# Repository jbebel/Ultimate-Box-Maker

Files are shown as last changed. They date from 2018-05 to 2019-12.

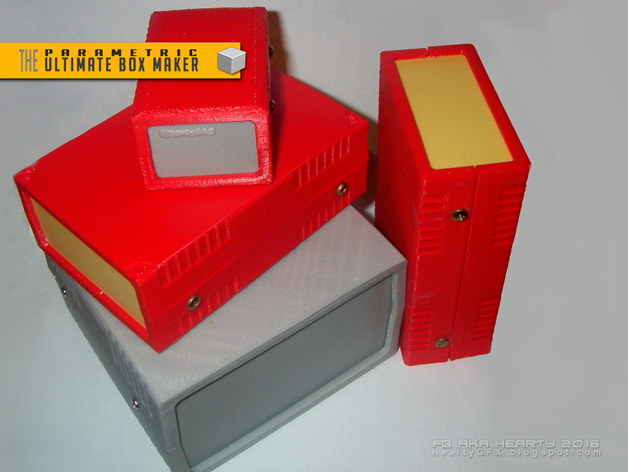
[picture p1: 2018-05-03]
images/dfdf5ceb28a5a7c63daad8bfc72fc554_preview_featured.jpg

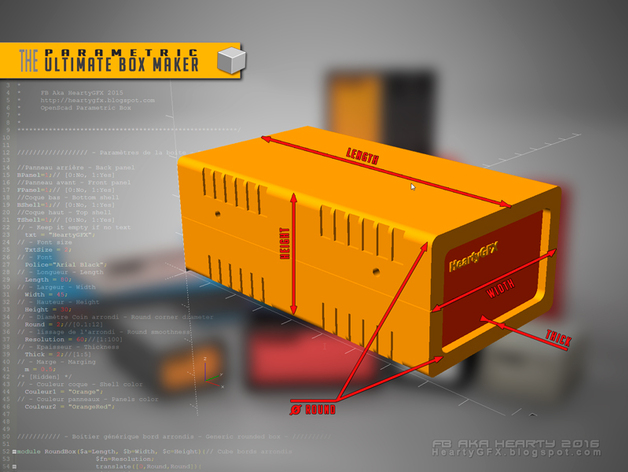
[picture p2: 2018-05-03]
images/5c2528d7dc69dc743380f6c7ddb887d5_preview_featured.jpg

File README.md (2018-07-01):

# Ultimate-Box-Maker
Ultimate Box Maker

This is copied from https://www.thingiverse.com/thing:1264391 under the creative commons license with modifications logged here.
It is publised as a remix on Thingiverse at https://www.thingiverse.com/thing:2938921

Box design originally by:
////////////////////////////////////////////////////////////////////
              -    FB Aka Heartman/Hearty 2016     -
              -   http://heartygfx.blogspot.com    -
              -       OpenScad Parametric Box      -
              -         CC BY-NC 3.0 License       -
////////////////////////////////////////////////////////////////////

Improved by jbebel:
http://github.com/jbebel/Ultimate-Box-Maker

To create a box, start by modifying the numerical parameters in the sections
below. This can be accomplished using a release of OpenSCAD newer than 2015.03.
As of the time of writing, this means that a development snapshot is required.
The Thingiverse Customizer may also potentially work, but at the time of
writing, it was inoperable.

The simplest choice is to hand-edit the .scad file. Feature toggles are
annotated with a comment. The other numerical parameters are measurements in
mm. Everything is parametrized, so if you double all the non-feature parameters
you will double the box size in every dimension. Certain parameters are derived
from other parameters. If you wish to override them, you may, but sensible
defaults have been chosen. Notably the design in this revision is particularly
PCB-centric, in that you should start with your PCB size and adjust the margins
around it to determine the box size. If you care more about the box size, you
can set the Length, Width, and Height explicitly, but read the comments around
them.

Once your box is sized appropriately, you can use the Panel modules to design
the holes and text for the front and back panels. Helper variables are provided
to assist you in positioning these holes relative to the PCB, if your holes are
for PCB-mounted components.

When you are ready to print, adjust the values in the "STL element to export"
section, and export each part one at a time.

Experimental options are provided for a screwless design, but these are
untested. In particular, the box fixation tabs may need thicknesses adjusted
in order to have the appropriate flexibility.

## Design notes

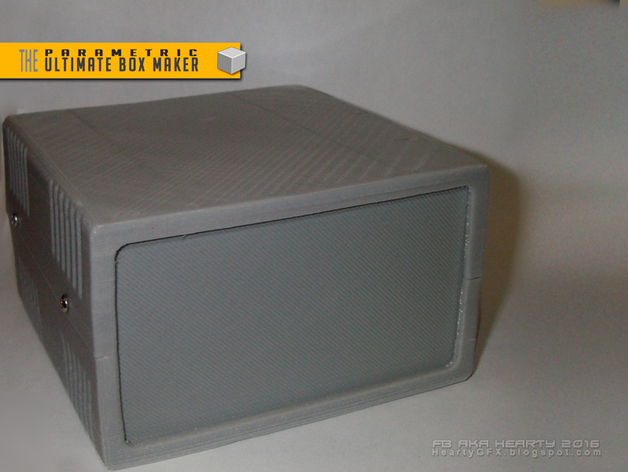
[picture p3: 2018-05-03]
images/74d1fa52020ccdc66438833ef1dfb658_preview_featured.jpg

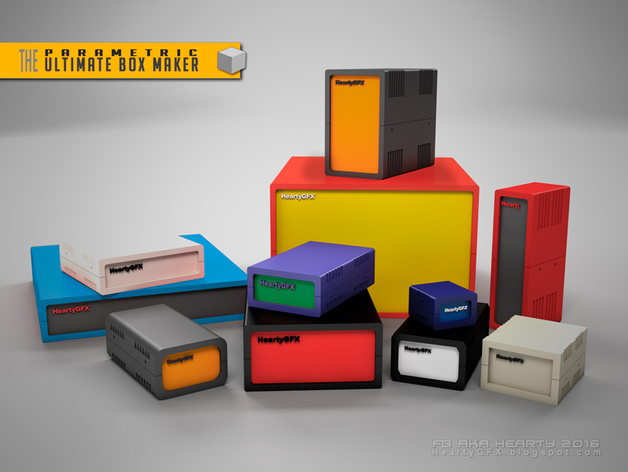
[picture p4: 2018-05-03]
images/bd4fbbd9aa4da913eb2d5eac3920107e_preview_featured.jpg

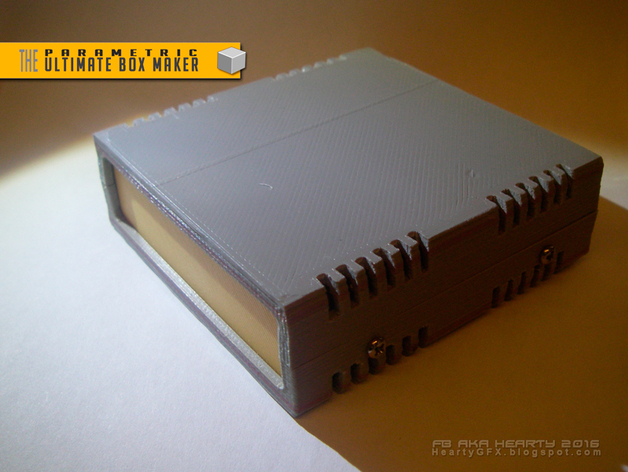
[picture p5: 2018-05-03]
images/9b60c601c6d0bcd0837e3c9c51fbf55f_preview_featured.jpg

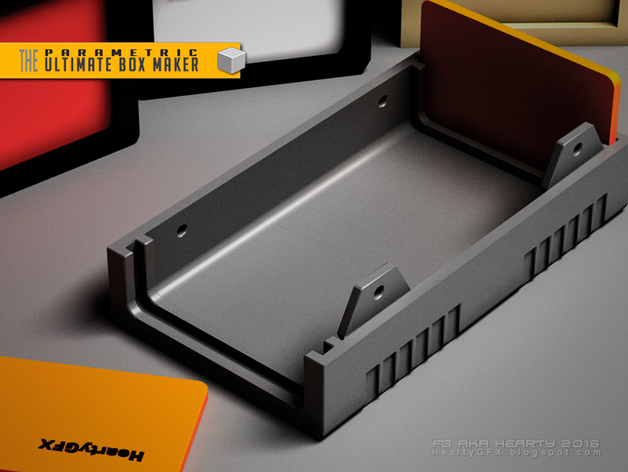
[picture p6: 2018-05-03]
images/7efb17c56cb85ef8a36d71741ac642c0_preview_featured.jpg

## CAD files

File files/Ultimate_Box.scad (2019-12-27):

/* Box design originally by:
////////////////////////////////////////////////////////////////////
              -    FB Aka Heartman/Hearty 2016     -
              -   http://heartygfx.blogspot.com    -
              -       OpenScad Parametric Box      -
              -         CC BY-NC 3.0 License       -
////////////////////////////////////////////////////////////////////

Improved by jbebel:
http://github.com/jbebel/Ultimate-Box-Maker

To create a box, start by modifying the numerical parameters in the sections
below. This can be accomplished using a release of OpenSCAD newer than 2015.03.
As of the time of writing, this means that a development snapshot is required.
The Thingiverse Customizer may also potentially work, but at the time of
writing, it was inoperable.

The simplest choice is to hand-edit the .scad file. Feature toggles are
annotated with a comment. The other numerical parameters are measurements in
mm. Everything is parametrized, so if you double all the non-feature parameters
you will double the box size in every dimension. Certain parameters are derived
from other parameters. If you wish to override them, you may, but sensible
defaults have been chosen. Notably the design in this revision is particularly
PCB-centric, in that you should start with your PCB size and adjust the margins
around it to determine the box size. If you care more about the box size, you
can set the Length, Width, and Height explicitly, but read the comments around
them.

Once your box is sized appropriately, you can use the Panel modules to design
the holes and text for the front and back panels. Helper variables are provided
to assist you in positioning these holes relative to the PCB, if your holes are
for PCB-mounted components.

When you are ready to print, adjust the values in the "STL element to export"
section, and export each part one at a time.

Experimental options are provided for a screwless design, but these are
untested. In particular, the box fixation tabs may need thicknesses adjusted
in order to have the appropriate flexibility.
*/

// preview[view:north east, tilt:top diagonal]
//----------------------- Box parameters ---------------------------

/* [Box options] */
// - Wall thickness
Thick = 2;
// - Panel thickness
PanelThick = 2;
// - Font Thickness
FontThick = 0.5;
// - Filet Radius
Filet = 2;
// - 0 for beveled, 1 for rounded
Round = 1; // [0:No, 1:Yes]
// - Printer margin around interior cutouts
CutoutMargin = 0.3;
// - Margin between mating parts
PartMargin = 0.1;
// - PCB feet? (x4)
PCBFeet = 1; // [0:No, 1:Yes]
// - Decorations?
Decorations = 1; // [0:No, 1:Yes]
// - Decorations to ventilation holes
Vent = 1; // [0:No, 1:Yes]
// - Decoration-Holes width (in mm)
Vent_width = 1.5;
// - Tolerance (Panel/rails gap on one edge)
PanelThickGap = CutoutMargin + PartMargin;
PanelVerticalGap = PartMargin;
PanelHorizontalGap = CutoutMargin + PartMargin;


/* [Box Fixation Tabs] */
// - Side screw hole (or snap) diameter
ScrewHole = 2.2606;
// - Screw thread major diameter for outer shell
BoxHole = 2.8448;
// Thickness of fixation tabs
TabThick = 2;
// Back left tab
BLTab = 1; // [0:Bottom, 1:Top]
// Back right tab
BRTab = 1; // [0:Bottom, 1:Top]
// Front left tab
FLTab = 1; // [0:Bottom, 1:Top]
// Front right tab
FRTab = 1; // [0:Bottom, 1:Top]
// EXPERIMENTAL: Snap tabs
SnapTabs = 0; // [0:Screws, 1:Snaps]


/* [PCB options] */
// - PCB Length
PCBLength = 80;
// - PCB Width
PCBWidth = 144;
// - PCB Thickness
PCBThick = 1.6;
// You likely need to maintain |TabThick| margin on the left and right for tabs
// and whatnot.
// - Margin between front panel and PCB
FrontEdgeMargin = 70;
// - Margin between back panel and PCB
BackEdgeMargin = 0;
// - Margin between left wall and PCB
LeftEdgeMargin = 11;
// - Margin between right wall and PCB
RightEdgeMargin = 11;
// - Margin between top of PCB and box top.
TopMargin = 84;


/* [PCB_Feet] */
// - Foot height above box interior
FootHeight = 8;
// - Foot diameter
FootDia = 8;
// - Hole diameter, or peg for screwless design
FootHole = 2.2606; // tap size for #4 coarse-thread
// - EXPERIMENTAL Screwless design
Screwless = 0; // [0:Screws, 1:Screwless]
FootFilet = FootHeight/4;

// Foot centers are specified as distance from PCB back-left corner.
// X is along the "length" axis, and Y is along the "width" axis.
// - Foot 1 distance from back PCB edge
Foot1X = 5;
// - Foot 1 distance from left PCB edge
Foot1Y = 5;
// - Foot 2 distance from back PCB edge
Foot2X = 5;
// - Foot 2 distance from right PCB edge
Foot2YFromEdge = 5;
Foot2Y = PCBWidth - Foot2YFromEdge;
// - Foot 3 distance from front PCB edge
Foot3XFromEdge = 5;
Foot3X = PCBLength - Foot3XFromEdge;
// - Foot 3 distance from left PCB edge
Foot3Y = 5;
// - Foot 4 distance from front PCB edge
Foot4XFromEdge = 5;
Foot4X = PCBLength - Foot4XFromEdge;
// - Foot 4 distance from right PCB edge
Foot4YFromEdge = 5;
Foot4Y = PCBWidth - Foot4YFromEdge;


/* [STL element to export] */
// - Top shell
TShell = 0; // [0:No, 1:Yes]
// - Bottom shell
BShell = 1; // [0:No, 1:Yes]
// - Front panel
FPanL = 1; // [0:No, 1:Yes]
// - Back panel
BPanL = 1; // [0:No, 1:Yes]
// - Panel holes and text
PanelFeatures = 0; // [0:No, 1:Yes]


/* [Hidden] */
// - Shell color
Couleur1 = "Orange";
// - Panel color
Couleur2 = "OrangeRed";
// - Text color
TextColor = "White";
// - making decorations thicker if it is a vent to make sure they go through
// shell
// Add a small number to Thick in case Filet is 0.
Dec_Thick = Vent ? Thick*1.001 + Filet : Thick/2;
// Separate vents with a square pillar by default.
Dec_Spacing = Thick + Vent_width;
// X offset to center of first vent
Dec_Offset = Thick*2 + PanelThick + PanelThickGap*2 + Dec_Spacing - Vent_width/2;

// Resolution based on Round parameter. Set this first number to something
// smaller to speed up processing. It should always be a multiple of 4.
Resolution = Round ? 100: 4;

/* Calculate box dimensions from PCB. If you want a more box-centric design
   where the outer diameter of the box matters more than the margins around
   the PCB you can set these manually. The PCB will still be placedaccording
   to the left and back margins, and if you want to use the screwless box
   design, you will need to set the TopMargin to
   (Height - Thick*2 - FootHeight - PCBThick)
*/
Length = PCBLength + FrontEdgeMargin + BackEdgeMargin + ((Thick + PanelThick + PanelThickGap*2)*2);
Width = PCBWidth + LeftEdgeMargin + RightEdgeMargin + Thick*2;
Height = FootHeight + PCBThick + TopMargin + Thick*2;
echo("Box: ", Length=Length, Width=Width, Height=Height);
// X position inset of mounting holes and tabs
MountInset = Thick*3 + PanelThick + PanelThickGap*2 + ScrewHole*4;

// Calculate panel dimensions from box dimensions.
PanelWidth = Width - Thick*2 - PanelHorizontalGap*2;
PanelHeight = Height - Thick*2 - PanelVerticalGap*2;


/*  Panel Manager

    Use the below 4 modules to produce holes and text on the front and back
    panels. The holes modules should contain instances of SquareHole or
    CylinderHole defined later in this file. The text modules should contain
    instances of LText or CText defined later in this file. It is
    recommended to use variables that you define for your needs to create
    the size and positions of these objects.
*/

// Calculate board-relative positions with respect to the panel, for
// convenience in placing panel elements.
TopOfBoardWRTPanel = FootHeight + PCBThick - PanelVerticalGap;
LeftEdgeOfBoardWRTFPanel = LeftEdgeMargin - PanelHorizontalGap;
LeftEdgeOfBoardWRTBPanel = RightEdgeMargin - PanelHorizontalGap;
// Visible panel edges
PanelBottomEdge = Thick - PanelVerticalGap;
PanelTopEdge = PanelHeight - Thick + PanelVerticalGap;
PanelLeftEdge = Thick - PanelHorizontalGap;
PanelRightEdge = PanelWidth - Thick + PanelHorizontalGap;


// Holes for front panel
module FPanelHoles() {
    // SquareHole(On/Off, Xpos,Ypos,Length,Width,Filet)
    SquareHole(1, 20, 20, 15, 10, 1);
    SquareHole(1, 40, 20, 15, 10, 1);
    SquareHole(1, 60, 20, 15, 10, 1);
    // CylinderHole(On/Off, Xpos, Ypos, Diameter)
    CylinderHole(1, 27, 40, 8);
    CylinderHole(1, 47, 40, 8);
    CylinderHole(1, 67, 40, 8);
    SquareHole(1, 20, 50, 80, 30, 3);
    CylinderHole(1, 93, 30, 10);
    SquareHole(1, 120, 20, 30, 60, 3);
}


// Text for front panel
module FPanelText() {
    // LText(On/Off, Xpos, Ypos, "Font", Size, "Text", "HAlign", "VAlign")
    LText(1, 20, 83, "Arial Black", 4, "Digital Screen", HAlign="left");
    LText(1, 120, 83, "Arial Black", 4, "Level", HAlign="left");
    LText(1, 20, 11, "Arial Black", 6, "  1     2      3", HAlign="left");
    // CText(On/Off, Xpos, Ypos, "Font", Size, Diameter, Arc(Deg), Starting Angle(Deg),"Text")
    CText(1, 93, 29, "Arial Black", 4, 10, 180, 0,
          ["1", "." , "3", "." , "5", "." , "7", "." , "9", "." , "11"]);
}
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

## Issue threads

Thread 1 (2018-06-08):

Make outer-shell screw holes larger

jbebel, 2018-06-08:
So that screws only firmly attach to inner box and can hold the outer box tightly in place.

Closed 2018-06-19.

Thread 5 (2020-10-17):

Adding some features

oiram55, 2020-10-17:
Hello,
here the box-maker with some add's

added air slots to Panels / Padding for text, if air slots are selected
Mounting holes on top
Cable holes on back
[U_Box_V103_M.zip](https://github.com/jbebel/Ultimate-Box-Maker/files/5396591/U_Box_V103_M.zip)

panel

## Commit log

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2018-05-03 Use consistent indenting
    Chose 4 spaces because the OpenSCAD editor uses that by default.
    [U_Box_V104_Test_Cleaned.scad]
2018-05-04 Put all if blocks in curly braces and use spacing
    Following style guide at https://www.thingiverse.com/thing:12768
    [U_Box_V104_Test_Cleaned.scad]
2018-05-04 Improve spacing
    Add/remove lots of spacing for consistency. Add/remove a few parenthesis
    for arithmetic readability.
    Actually undo previous spacing because I disagree with the style guide
    referenced previously.
    [U_Box_V104_Test_Cleaned.scad]
2018-05-04 Call all functions in a consistent style.
    Fixed a few minor issues in the process (typoed "square" in previous
    commit")
    Put curly braces around blocks that didn't have them for consistency.
    Notably, re-ordered arguments for "cylinder" since the manual says if
    you have named arguments, all following arguments must be named. So now
    all cylinders have the height first, unnamed, followed by either r= or
    d=, and then $fn= if it isn't otherwise specified in the block.
    [U_Box_V104_Test_Cleaned.scad]
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2018-05-04 Add module documentation
    Before each module, describe the function and inputs
    Also added a few comments identifying block endings.
    Added a missing space after a "for".
    [U_Box_V104_Test_Cleaned.scad]
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2018-05-06 Add editable back panel support
    Holes and letters can be added to the back the same as the front.
    Calculate PanelWidth and PanelHeight from parameters and use globally.
    [U_Box_V104_Test_Cleaned.scad]
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2018-05-07 Calculate dimensions from PCB and margins
    Add parameters for PCB size and margins on all sides.
    Generate the box dimensions from these sizes.
    Place the PCB appropriately based on the margins.
    This has a change in definition, as the previous PCB size was the size
    of the square made by the mounting holes. Now it is the size of the
    actual PCB.
    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
    [U_Box_V104_Test_Cleaned.scad]
2018-05-07 minor fixes
    Removed parens for style consistency.
    Fixied call to color() to be consistent with other calls.
    [U_Box_V104_Test_Cleaned.scad]
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2018-05-07 Calculate foot positions parametrically
    Add paramaters for X and Y positions of all 4 feet.
    Use those when creating feet relative to the board position.
    [U_Box_V104_Test_Cleaned.scad]
2018-05-08 Use FootHeight as height above box interior.
    It is also the depth of the screw hole, which is likely how it will be
    calculated.
    [U_Box_V104_Test_Cleaned.scad]
2018-05-08 Add a PCBThick parameter
    Use it to calculate the top margin from the top of the board.
    Draw the transparent board with appropriate thickness
    Provide convenience variables for board position on panel.
    [U_Box_V104_Test_Cleaned.scad]
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2018-05-08 Set hole sizes and CutoutMargin
    Add ScrewHole and FootHole parameters
    Set them to #4 coarse thread size.
    Use them in appropriate places on tabs and feet
    Add CutoutMargin parameter as a margin around interior cutouts.
    Apply it to foot, CylinderHole, and SquareHole
    [U_Box_V104_Test_Cleaned.scad]
2018-05-09 Remove Thick = Thick*2
    The Coque module was setting Thick = Thick*2 which causes confusion
    while reading, likelihood of errors, and difficulty in modification.
    I removed this, and replace every invocation with Thick*2, simplifying
    where appropriate. This is largely in preparation of separating Panel
    thickness from Thick.
    [U_Box_V104_Test_Cleaned.scad]
2018-05-09 Center the interior box
    The interior box (fins for holding the panel) was oddly not centered.
    Shift it using the proper parameters for it to be centered.
    It also was shifted vertically by 0.1 to remove "the artifact" I'm not
    sure what this artifact is, so I'm removing the shift until I see reason
    not to. It also makes the interior hole of the feet shorter by 0.1 and
    the tolerance under the board 0.1 less, so it seems a bit wrong to have
    in place.
    [U_Box_V104_Test_Cleaned.scad]
2018-05-09 Large rail box decreased in vertical height.
    While it has no impact on the outcome, the large outer box was taller
    than it needed to be, and didn't accurately represent the box size when
    debugged. This was probably an error of the Thick = Thick*2 change.
    [U_Box_V104_Test_Cleaned.scad]
2018-05-09 Scale upper cutout cube to thickness
    Rather than fixed 100
    [U_Box_V104_Test_Cleaned.scad]
2018-05-09 Also fix height of interior through-box
    [U_Box_V104_Test_Cleaned.scad]
2018-05-09 Remove some unnecessary shifting of cutouts
    The 45 degree box for the bottom angled cutout of the box tabs was
    unnecessarily shifted.
    The rectangular cutout for the sides of the tabs was unnecessarily wide,
    and the margin depended on the thickness, which doesn't make much sense.
    It depends more on the printer, so this margin should be parametrized in
    a later CL.
    [U_Box_V104_Test_Cleaned.scad]
2018-05-09 Support PanelThick different from Thick
    If PanelThick is equal to Thick, all is the same. If it is different,
    then only the ends are scaled. Everything in the middle, including box
    decorations and feet remain in the same position relative to the
    interior of the panels.
    [U_Box_V104_Test_Cleaned.scad]
2018-05-09 Fix position of front panel
    [U_Box_V104_Test_Cleaned.scad]
2018-05-09 Center box decorations on the box.
    Previously they were shifted to the front by half the vent width. This
    should be better parametrized still. Particularly the closeness to the
    edge.
    [U_Box_V104_Test_Cleaned.scad]
2018-05-09 Support taller feet
    Make the foot exterior cutout square as tall as FootHeight.
    Previously making it taller than 100 made the top wider.
    This is obviously ridiculous, but no harder to do right, and looks nicer
    when debugging.
    [U_Box_V104_Test_Cleaned.scad]
2018-05-09 Support FootFilet in parameters
    Default it to Thick so it scales with the box.
    [U_Box_V104_Test_Cleaned.scad]
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2018-05-09 Shorten some long lines.
    [U_Box_V104_Test_Cleaned.scad]
2018-05-09 Support holes in thicker panels
    Panel cutouts were limited to 10mm. Scale them by PanelThick to make
    debugging more appealing and support ridiculously thick panels.
    [U_Box_V104_Test_Cleaned.scad]
2018-05-14 Minor spacing fixes.
    [U_Box_V104_Test_Cleaned.scad]
2018-05-14 Add a boolean parameter for Round
    Use it to set either a round or beveled corner. Use it for RoundBox,
    Panel, and the feet edge.
    Set all other circles (except the tabs) to fn=100 for smoothness.
    [U_Box_V104_Test_Cleaned.scad]
2018-05-14 Add comment for Round parameter
    With this comment, it appears as a boolean in the customizer.
    [U_Box_V104_Test_Cleaned.scad]
2018-05-14 Remove an extra echo and fix spacing/comments
    [U_Box_V104_Test_Cleaned.scad]
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2018-05-14 Stop translating text by 0.5 and back again.
    I suspect this was an artifact before text was linear_extruded, as it
    has a default thickness of 1, so shifting by 0.5 placed it on the
    surface. Linear extrude was added, and then the calls to LText and CText
    were shifted the other direction by 0.5 to get them on the surface. This
    now just results in two unnecessary translates, so I've removed them.
    I also removed the shift from the "PCB" text. It's thickness has no
    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
    [U_Box_V104_Test_Cleaned.scad]
2018-05-14 Unify text() arguments.
    Re-order arguments to match docs and be consistent.
    Remove valign from CText, as baseline was the default value.
    Remove an unnecessary space.
    [U_Box_V104_Test_Cleaned.scad]
2018-05-14 Support VAlign for LText
    Add new argument that defaults to baseline.
    Update comments to describe the new option.
    Update some HAlign documentation with more details.
    [U_Box_V104_Test_Cleaned.scad]
2018-05-14 fix ridiculous font thickness used in testing
    [U_Box_V104_Test_Cleaned.scad]
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2018-05-15 Re-work of vent/decoration holes
    Make all vent holes Thick + Filet thick so they extend to the end of the
    rounded corner, particularly for large filets, but not too far in for
    small filets.
    Make all decorations Thick/2 so they scale with the thickness.
    Separate the vents by a square Thick x Thick pillar.
    Generate the position of the first vent/decoration based on the panel
    thickness, wall thickness, margin, and vent spacing so that there is one
    pillar's width beteween the interior edge and the first vent.
    Bring the decoration/vent in from 1mm outside the box both horizontally
    and vertically to prevent artifacts. This does result in vents reaching
    under the box farther than previously, bu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
    [U_Box_V104_Test_Cleaned.scad]
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2018-05-16 Re-work panel, roundbox, and SquareHole
    Do the minkowski in 2D so that if Filet is 0, and half the minkowski is
    null, you don't have to fix the height. Then translate, extrude, and
    rotate it.
    [U_Box_V104_Test_Cleaned.scad]
2018-05-16 Use "offset" instead of minkowski with a circle
    The last change didn't work if Filet is 0. minkowski didn't work well
    with a 2D null argument either. This is a better solution, plus it saves
    a line.
    The preview works fine, but there's still an issue with the full render.
    [U_Box_V104_Test_Cleaned.scad]
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2018-05-16 Improve subtraction on interior rails
    There was some artifacting and errors resulting from the inner rails not
    producing a valid 2-manifold object. Make the rails larger so they
    interect the box, and make the subtraction the full height and width of
    the box so the boundary isn't indeterminate.
    [U_Box_V104_Test_Cleaned.scad]
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2018-05-16 Adjust holes based on wall thickness
    Rather than fixed at 20mm, these are now sized based on wall thickness,
    supporting arbitrary wall thickness, and making debug views more
    appealing.
    [U_Box_V104_Test_Cleaned.scad]
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2018-05-16 Make it go to 11. Also fix the CText angles.
    [U_Box_V104_Test_Cleaned.scad]
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2018-05-16 Parametrize the box fixation tabs
    This is the last part to make the box fully scalable. Now if you double
    every parameter, the box doubles in all dimensions. The panel features
    are not changed, however. That's up to you to fix.
    The tab cutouts are now scaled off of the screw hole size, since that
    fixes the diameter of the tab.
    I've also added an OuterMargin which adjusts the spacing you need
    between the tab and the box wall. This is a property of your printer,
    and shouldn't be changed when you scale other aspects of the box. I
    might base other dimensions, like the panel gap on this value as well.
    [U_Box_V104_Test_Cleaned.scad]
2018-05-18 Split up the man box code into modules
    The Coque module is now very simple and self-commenting about what it
    does. The complexity is in the referenced modules, which are much
    shorter and easier to read. I'll split things up just a bit more, but
    wanted to check this in first.
    [U_Box_V104_Test_Cleaned.scad]
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2018-05-22 Produce fixation leg in separate module
    [U_Box_V104_Test_Cleaned.scad]
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2018-05-23 Put top shell and bottom shell in separate modules
    Make the Coque module generic, adding specific changes to a separate
    TopShell and BottomShell module. The color() function is moved to Coque
    to prevent coloring the PCB model. I left the legs and holes in the
    separate modules to prepare for more customization of them for top and
    bottom.
    [U_Box_V104_Test_Cleaned.scad]
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2018-05-23 Support arbitrary legs on top/bottom shell
    Add BLLeg, FLLeg, BRLeg, and FRLeg parameters where 0 means put that leg
    on the bottom shell, and 1 means put it on the top. Call the legs and
    hols modules with a "top" argument where 0 means build the bottom shell
    legs/holes, and 1 means build the top. Gate each leg or hole creation
    based on logic between XXLeg and top.
    This also required making the top shell using mirror() rather than
    rotate, since that kept the same leg/hole in the same position when
    flipped to the top.
    [U_Box_V104_Test_Cleaned.scad]
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2018-05-24 Support experimental snap tabs
    Set SnapTabs to 1 and get tabs with buttons and semispherical holes in
    the box. This is experimental because I haven't built a box like this
    and don't know how well it will work. The thickness of the tab is
    probably important since you need it to flex just the right amount to
    allow the button to fit. Also, the ScrewHole value is used for the size
    of the button, so it should not exceed 2*Thick.
    [U_Box_V104_Test_Cleaned.scad]
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2018-05-27 Fix spacing in logic expressions
    [U_Box_V104_Test_Cleaned.scad]
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2018-05-27 Rework the margins
    Change CutoutMargin from a diameter to a radius/single edge (cut it in half)
    Change OuterMargin to a more generic part margin for mating parts
    Derive PanelGap from CutoutMargin and OuterMargin
    [U_Box_V104_Test_Cleaned.scad]
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2018-05-29 Add experimental screwless PCB feet
    If Screwless is true, use feet with a peg in them that goes through the
    PCB holes. Feet then come down from the top shell to press against the
    PCB and hold it in place. These have a hole in the center so the peg
    from the bottom shell will insert into it and keep the shells in a
    stable position in the X-Y plane. If you combine this with screwless
    snap tabs, you can have a fully screwless box.
    [U_Box_V104_Test_Cleaned.scad]
2018-05-29 Clean up comments and add inline documentation
    Major cleanup of commenting for style and completeness.
    Also removed TopMargin and replaced it with TopPCBMargin, as nothing was
    using TopMargin other than Height.
    [U_Box_V104_Test_Cleaned.scad]
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2018-07-01 Separate the X and Y/Z gaps around the panel
    The panel gap didn't need to be as large around the outer edge, so call
    that PanelEdgeGap and default it to PartMargin*2. Leave the thickness
    margin at CutoutMargin*2 + PartMargin*2 and rename it to PanelThickGap.
    [Ultimate_Box.scad]
2018-07-01 Minor fixes to snap tabs
    Shrink the button size so it fits inside the outer divet with a margin
    of PartMargin, rather than giving both the same radius.
    Cut off the button sphere at a more accurate position in case the tab
    thickness is smaller than half the button radius.
    [Ultimate_Box.scad]
2018-07-20 Separate horizontal and vertical panel gaps
    Turns out we still need more in the horizontal due to cutout margins at
    the bottom of the slot. This isn't needed in the vertical. Separating
    these lets us give more horizontal gap again without sacrificing tight
    vertical tolerancees.
    [Ultimate_Box.scad]
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2019-04-11 Add missing parameters to fix warnings
    [Ultimate_Box.scad]
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
